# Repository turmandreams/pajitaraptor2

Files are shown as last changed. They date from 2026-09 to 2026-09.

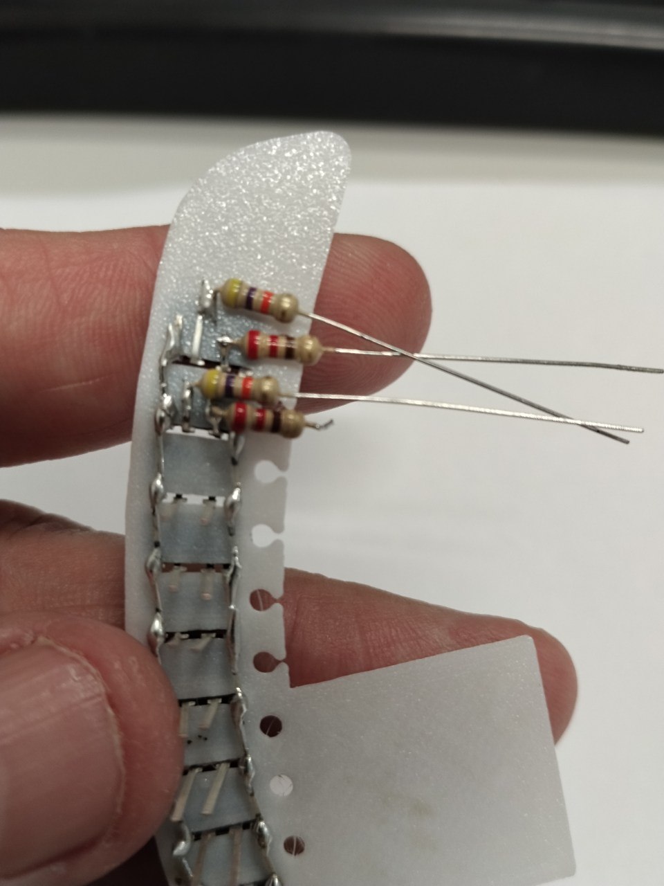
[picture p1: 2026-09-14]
images/06.jpg

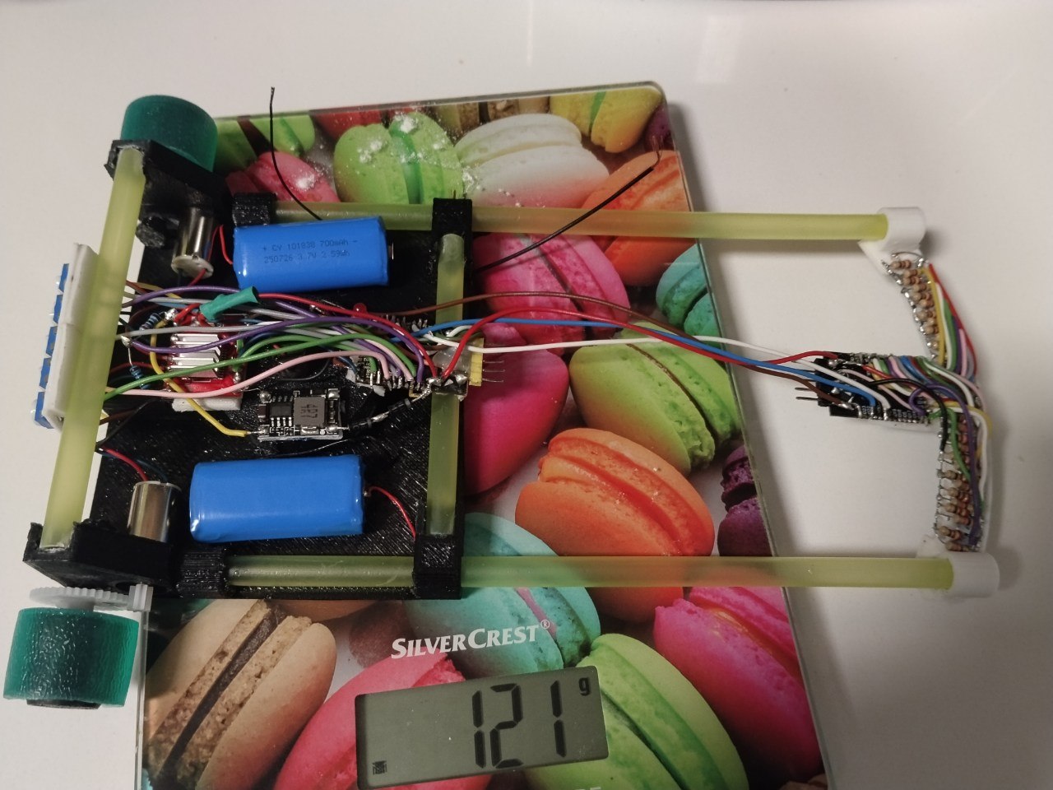
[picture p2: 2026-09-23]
images/32.jpg

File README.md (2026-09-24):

INFORMACIÓN
----------------------

Pajitaraptor 2.0 es un robot siguelineas evolución de Pajitaraptor. La idea es hacer un robot siguelineas lo más rápido posible con los componentes que tengo actualmente.

En este repositorio, voy a poner todos los archivos 3D, código fuente , esquemáticos, fotografías y vídeos explicativos del proceso de construcción del robot. 

Si el robot funciona bien, en el futuro realizaré una PCB, para que sea más fácil replicarlo...

PAJITARAPTOR 2.0 VIDEOS
----------------------

(https://www.youtube.com/shorts/T2Jo6v5rl2A)) 

(https://www.youtube.com/shorts/CzJLmVulj7A)) 

(https://www.youtube.com/shorts/VmxY9THQH6k)) 

(https://www.youtube.com/shorts/2Kd2S3cPOpA)) 

(https://www.youtube.com/shorts/im3EgLPvTIs)) 

(https://www.youtube.com/shorts/bMzzeWZkE-k)) 

(https://www.youtube.com/shorts/C7v8effX4s4)) 

(https://www.youtube.com/shorts/2WoTrkFVUT8)) 

(https://www.youtube.com/shorts/3bNs3Pc4z7s)) 

(https://www.youtube.com/shorts/3i1-s1l6Brc))

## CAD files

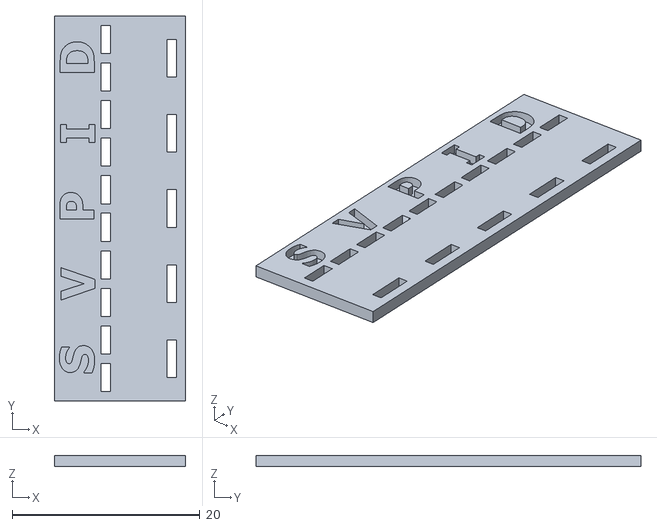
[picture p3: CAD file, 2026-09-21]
stl/pot.stl
14.0 x 41.0 x 1.20

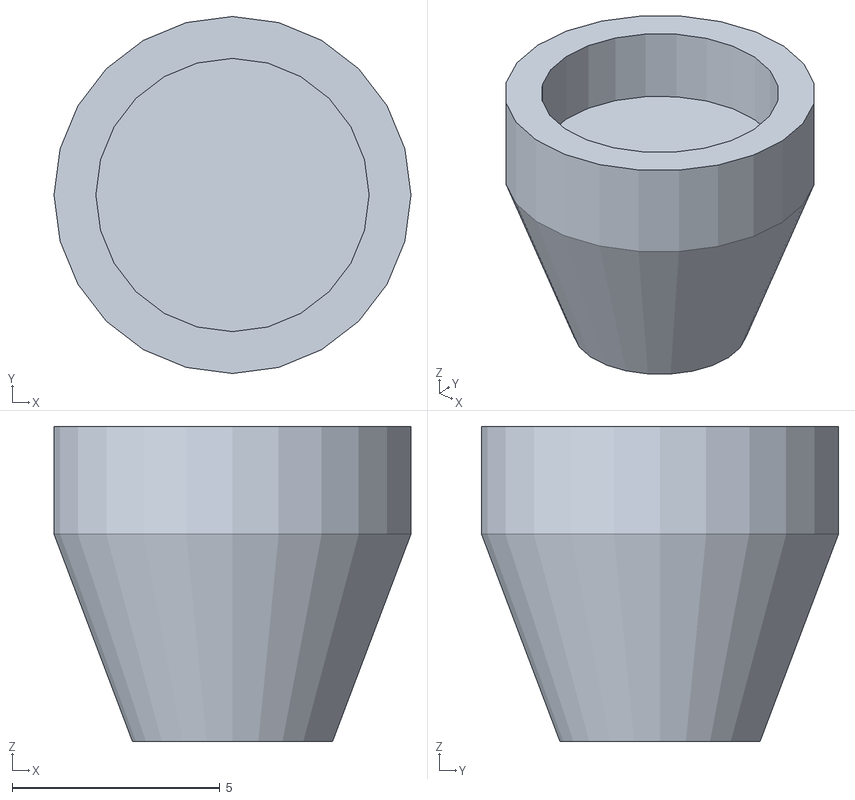
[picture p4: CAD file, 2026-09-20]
stl/imanes.stl
8.60 x 8.60 x 7.60

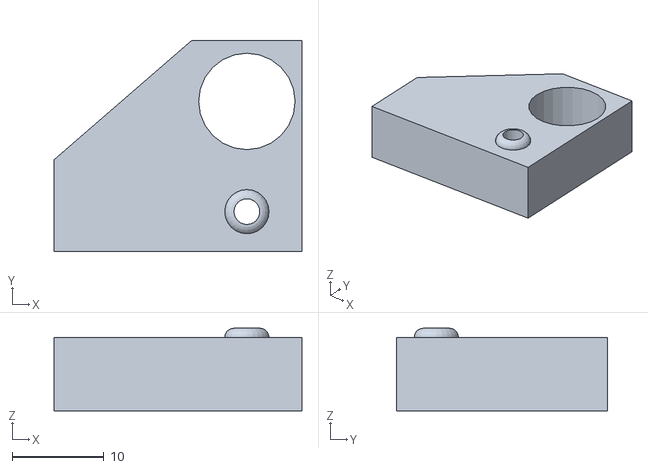
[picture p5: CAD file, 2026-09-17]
stl/soportemotorI.stl
27.0 x 23.0 x 9.00

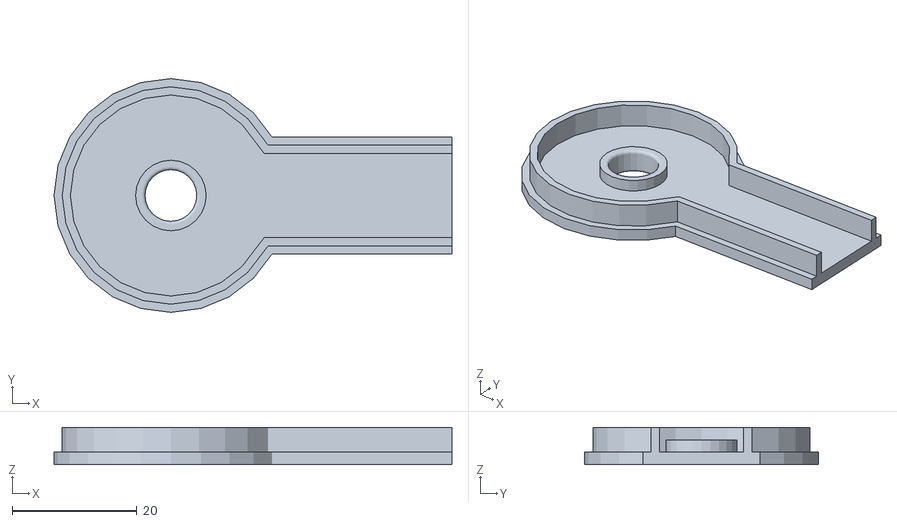
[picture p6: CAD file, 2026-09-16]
stl/tapaventilador.stl
63.7 x 37.4 x 6.00

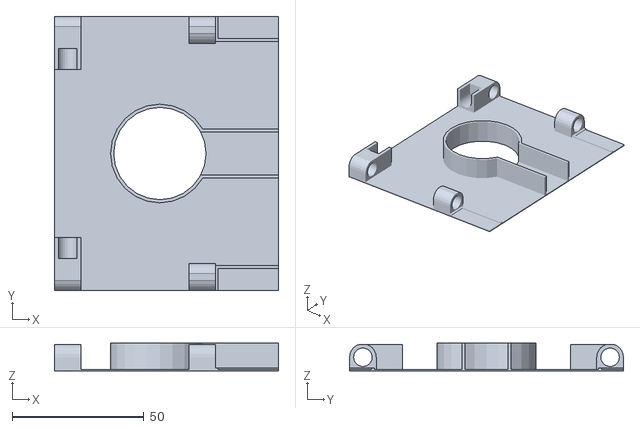
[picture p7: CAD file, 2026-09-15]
stl/base.stl
85.0 x 103.9 x 10.6

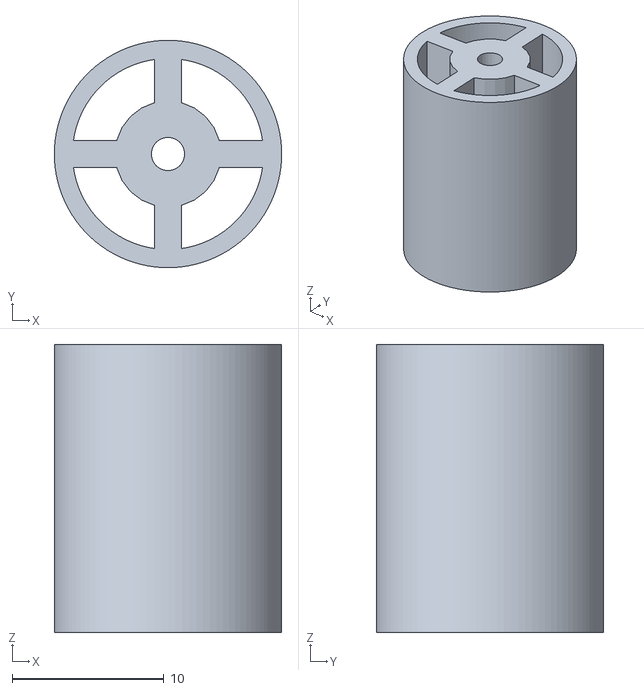
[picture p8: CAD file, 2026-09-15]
stl/rueda.stl
15.0 x 15.0 x 19.0

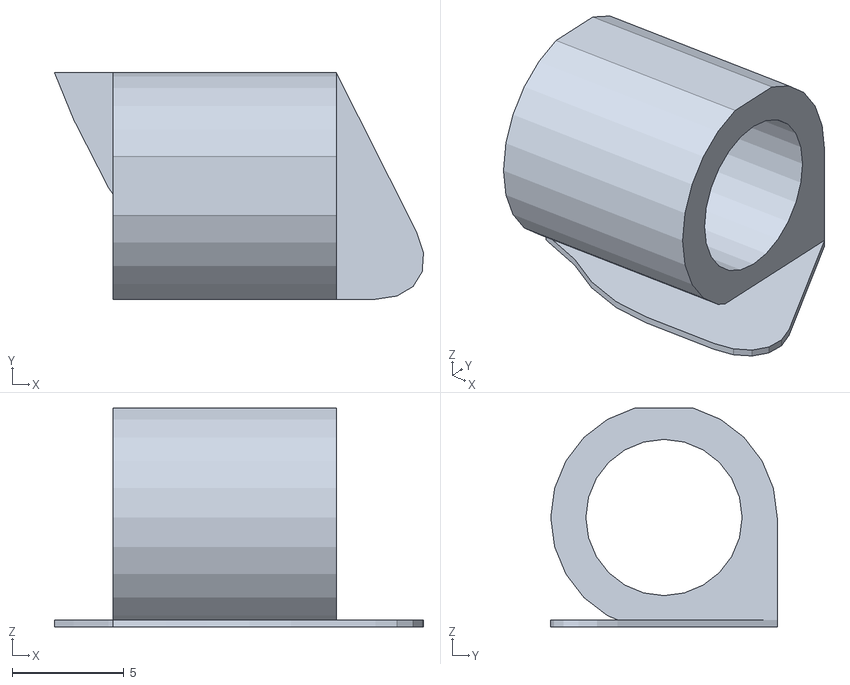
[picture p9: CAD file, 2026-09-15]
stl/soportepajitaDI.stl
16.5 x 10.1 x 9.80

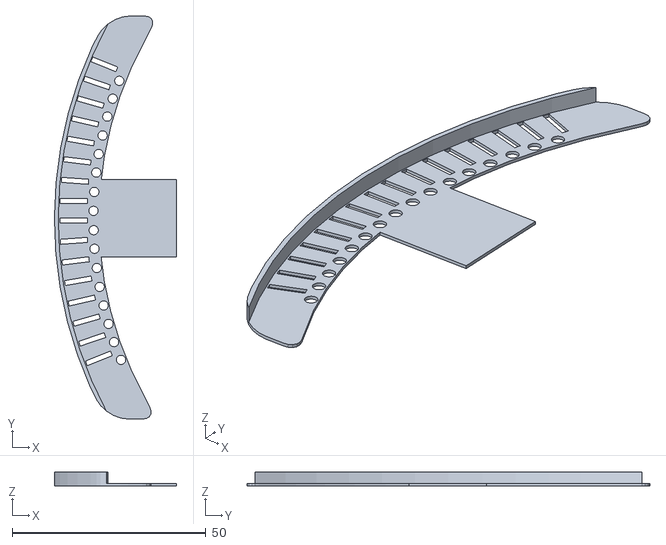
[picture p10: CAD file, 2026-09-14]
stl/arraysensores.stl
31.5 x 103.9 x 3.60

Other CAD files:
stl/soportemotorD.stl
stl/soportepajitaDD.stl
stl/arraysensores.skp
stl/base.skp
stl/imanes.skp
stl/pot.skp
stl/rueda.skp
stl/soportemotorD.skp
stl/soportemotorI.skp
stl/soportepajitaDD.skp
stl/soportepajitaDI.skp
stl/tapaventilador.skp

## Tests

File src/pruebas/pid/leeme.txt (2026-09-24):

 Detalles importantes

Sentido de giro: si al poner solo Kp el robot se aleja de la línea en lugar de corregir, cambia el signo (velIzq = VEL_BASE - correccion, velDer = VEL_BASE + correccion). Lo mismo si un motor gira al revés: intercambia sus IN1/IN2.
Pines ADC: usa pines de ADC1 (GPIO 32–39) para los potenciómetros. ADC2 deja de funcionar si activas WiFi o Bluetooth.
Versión del core: ledcAttach(pin, freq, res) y ledcWrite(pin, duty) son de la versión 3.x. Si usas la 2.x, sería ledcSetup(canal, freq, res) + ledcAttachPin(pin, canal) y ledcWrite(canal, duty).
Marcha atrás: permito velocidades negativas para que en curvas cerradas una rueda pueda frenar o invertir. Si no lo quieres, cambia el constrain a 0, 255.

Cómo ajustarlo con los potenciómetros

Pon Ki y Kd a cero. Sube Kp hasta que el robot siga la línea pero oscile.
Sube Kd poco a poco hasta que desaparezcan las oscilaciones.  
Ki normalmente se deja a cero o muy bajo en siguelíneas. Solo ayuda si el robot tiende a ir siempre desplazado hacia un lado.
Cuando lo tengas estable, sube VEL_BASE y reajusta.

Si ves que el potenciómetro de Kp o Kd se queda corto (o que todo el ajuste útil ocurre en una zona muy pequeña del giro), cambia KP_MAX o KD_MAX para ganar resolución donde la necesitas.

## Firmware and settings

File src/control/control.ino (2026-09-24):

#include <Wire.h>

#define SDA_PIN 21
#define SCL_PIN 26
#define SLAVE_ADDR 0x08

const int pinled=2;

const int pinAIN1 = 4;
const int pinAIN2 = 16;
const int pinPWMA = 17;


const int pinBIN1 = 15;
const int pinBIN2 = 12; 
const int pinPWMB = 27;  


const int pinsuccion = 13;  

const int frecuencia = 20000; 
const int resolucion = 8;    

// Asignación de canales de hardware obligatorios en v2.x
const int canalMotorA = 0;
const int canalMotorB = 1;


// ---------- Rangos máximos de cada constante ----------
// Kp: con error 750 y Kp=0.5 -> corrección 375 (satura sobrada)
const float KP_MAX = 0.5;
const float KI_MAX = 0.005;
const float KD_MAX = 5.0;

// ---------- Parámetros del robot ----------
int   VEL_BASE = 150;      // velocidad en recta (0..255)
const float INTEGRAL_MAX = 20000; // anti-windup

float Kp = 0, Ki = 0, Kd = 0;
float integral = 0;
float errorAnterior = 0;
unsigned long tAnterior = 0;
unsigned long tPots = 0;

const int canalSuccion = 2;

const int pinBateria = 36; 

// Factor para R1=220k y R2=100k -> (220+100)/100 = 3.2
const float factorDivisor = 3.2; 

// Voltaje de referencia real del ESP32 (típicamente 3.3V)
const float VREF = 3.3; 


volatile float receivedFloat = 0.0f;
volatile bool newData = false;

int contador=-1;

int tiempo=0;

int succion = 0;
int p_pid = 0;
int i_pid = 0; 
int d_pid = 0;

int tiemposensores=0;

boolean corre=false;




void medirbateria(){

 int valorADC = analogRead(pinBateria);
  
  // Convertir el valor de 8 bits (0-255) a voltaje en el pin (0 - 3.3V)
  float voltiosPin = (valorADC * VREF) / 255.0;
  
  // Calcular el voltaje real de la batería usando el divisor de tensión
  float voltajeBateria = voltiosPin * factorDivisor;
  
  // Calcular el porcentaje de carga (Batería 2S: 6.4V vacía a 8.4V llena)
  float porcentaje = ((voltajeBateria - 6.4) / (8.4 - 6.4)) * 100.0;
  
  // Limitar el porcentaje entre 0 y 100%
  if (porcentaje > 100) porcentaje = 100;
  if (porcentaje < 0) porcentaje = 0;

  // Imprimir los resultados
  Serial.print("Lectura ADC (8-bit): ");
  Serial.print(valorADC);
  Serial.print(" | Voltaje Batería: ");
  Serial.print(voltajeBateria, 2);
  Serial.print(" V | Carga: ");
  Serial.print(porcentaje, 0);
  Serial.println("%");

  
}

void leepotenciometros(){
  
    unsigned long sumS = 0;
    unsigned long sumV = 0;
    unsigned long sumP = 0;
    unsigned long sumI = 0;
    unsigned long sumD = 0;

    for(int k = 0; k < 100; k++){
        sumS += (255-analogRead(34));
        sumV += (255-analogRead(35));
        sumP += (255-analogRead(32));
        sumI += (255-analogRead(33));
        sumD += (255-analogRead(39));
    }

    succion = sumS / 100;
    VEL_BASE = sumV / 100;
    p_pid = sumP / 100;
    i_pid = sumI / 100;
    d_pid = sumD / 100;


    Kp = p_pid / 255.0 * KP_MAX;
    Ki = i_pid / 255.0 * KI_MAX;
    Kd = d_pid / 255.0 * KD_MAX;

    
    // Mostrar resultados en el Monitor Serie
    Serial.print("Succion : "); Serial.println(succion);
    Serial.print("Velocidad Base: "); Serial.println(VEL_BASE);
    Serial.print("P : "); Serial.println(p_pid);
    Serial.print("I : "); Serial.println(i_pid);
    Serial.print("D : "); Serial.println(d_pid);
    Serial.println("");
    
    
    //ponemos el pwm en el ventilador de succion
    if(succion<20){ succion=0;}
    succion=succion/5;
    
    
    
}

// velocidad: -255..255 (negativo = marcha atrás)
void motor(int canal, int in1, int in2, int velocidad) {
  velocidad = constrain(velocidad, -255, 255);
  if (velocidad >= 0) {
    digitalWrite(in1, HIGH);
    digitalWrite(in2, LOW);
  } else {
    digitalWrite(in1, LOW);
    digitalWrite(in2, HIGH);
  }
  ledcWrite(canal,abs(velocidad));
}

void pidmotores(float error){

  unsigned long ahora = micros();
  float dt = (ahora - tAnterior) / 1000.0;   // en milisegundos
  tAnterior = ahora;
  if (dt <= 0) dt = 1;


  // --- PID ---
  integral += error * dt;
  integral = constrain(integral, -INTEGRAL_MAX, INTEGRAL_MAX);

  float derivada = (error - errorAnterior) / dt;
  errorAnterior = error;

  float correccion = Kp * error + Ki * integral + Kd * derivada;

  // --- Aplicar a motores ---
  int velIzq = VEL_BASE + correccion;
  int velDer = VEL_BASE - correccion;

  motor(canalMotorA,pinAIN2,pinAIN1, velIzq);
  motor(canalMotorB,pinBIN1,pinBIN2, velDer);

  ledcWrite(canalSuccion,succion);
    
}

void receiveEvent(int bytesCount) {
  
  // Comprobamos que hayan llegado exactamente 4 bytes (tamaño de un float)
  if (bytesCount == sizeof(float)) {
  
    digitalWrite(pinled,HIGH);
    corre=true;

  
    uint8_t buffer[sizeof(float)];
    
    for (int i = 0; i < sizeof(float); i++) {
      buffer[i] = Wire.read();
    }
    
    // Copiamos los bytes directamente a la variable float en memoria
    memcpy((void*)&receivedFloat, buffer, sizeof(float));

    pidmotores(receivedFloat);

    tiemposensores=millis();

/*
    contador++;

    //Serial.println(receivedFloat, 2);
    if(contador==0){  tiempo=millis(); }
    else if(contador==100){
        contador=-1;
        int valor=millis()-tiempo;
        Serial.print("Ha tardado : ");
        Serial.println(valor);
        Serial.print("Posicion : ");
        Serial.println(receivedFloat, 2);
    }
*/
    
  } else {
    // Si llegan bytes extras, vaciamos el bus
    while (Wire.available()) Wire.read();
  }

  
}

void espera(int t){
  boolean estado=corre;
  for(int i=0;i<t;i++){
        if(corre){
            if((millis()-tiemposensores)>10){ 
              corre=false;
              digitalWrite(pinled,LOW);              
            }
        }
        
        if(estado!=corre){ break; }
        delay(1);
  }
  
}

void setup() {
  
  Serial.begin(115200);
 
  pinMode(pinAIN1, OUTPUT);
  pinMode(pinAIN2, OUTPUT);
  pinMode(pinBIN1, OUTPUT);
  pinMode(pinBIN2, OUTPUT);
  pinMode(pinPWMA, OUTPUT);
  pinMode(pinPWMB, OUTPUT);

  
  ledcSetup(canalMotorA, frecuencia, resolucion); 
  ledcSetup(canalMotorB, frecuencia, resolucion); 
  ledcSetup(canalSuccion, frecuencia, resolucion); 
  
  
  ledcAttachPin(pinPWMA, canalMotorA); 
  ledcAttachPin(pinPWMB, canalMotorB); 

  ledcAttachPin(pinsuccion,canalSuccion); 
  
  pinMode(pinled,OUTPUT);
  digitalWrite(pinled,LOW);
    
  analogReadResolution(8); 

  delay(2000);
  leepotenciometros();
  delay(2000);
  
  Wire.begin(SLAVE_ADDR, SDA_PIN, SCL_PIN, 1000000);
  Wire.onReceive(receiveEvent);
  
}

void loop() {

  /*
  if(corre){

    ledcWrite(canalMotorA, velocidad); 
    ledcWrite(canalMotorB, velocidad); 

    //Hacia atras
    digitalWrite(pinAIN2, LOW);
    digitalWrite(pinAIN1, HIGH);
    digitalWrite(pinBIN1, LOW);
    digitalWrite(pinBIN2, HIGH);
    espera(2000); 

  }
*/
  espera(2);
  
  if(!corre){

    leepotenciometros();
    medirbateria();
    
    motor(canalMotorA,pinAIN2,pinAIN1,0);
    motor(canalMotorB,pinBIN1,pinBIN2,0);
    ledcWrite(canalSuccion,0);
    espera(100); 
    
  }
  
  
}

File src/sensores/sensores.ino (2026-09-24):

#include <Arduino.h>
#include <IRremoteESP8266.h>
#include <IRrecv.h>
#include <IRutils.h>


const uint16_t RECV_PIN = 5; 

IRrecv irrecv(RECV_PIN);
decode_results results;
const int pinled=19;

#include <Wire.h>

#define SDA_PIN 21
#define SCL_PIN 22
#define SLAVE_ADDR 0x08
#define I2C_SPEED 1000000  // 1 MHz (Fast Mode+)

int pines[]={36,39,34,35,32,33,25,26,27,14,12,13,15,2,0,4};

float posicion=0.0;

boolean funcionando=false;

int tiempo=0;

int tiempoparpadeo=0;
boolean ledparpadeo=false;


void leesensores(){
    
    float sensores[16];
    float suma = 0;
    float sumaPesos = 0;

    int val=0;

   // String dato="";
    
    for(int i=0;i<16;i++){      
        val=255-analogRead(pines[i]);
      //  dato+=val;
        sensores[i]=(float)val;
     //   if(i!=15){ dato+=","; }
    }
    
  //  Serial.println(dato);

   
    int peso=-8.0;

    int num=0;
    for (int i = 0; i < 16; i++) {        
                
        if(sensores[i]>30){ 
          suma += sensores[i];
          sumaPesos += sensores[i] * peso;  
          num++;
        }
        peso++;        
    }

        
    float posicion2 = sumaPesos/suma;
    if(num!=0){  
        posicion=(posicion2*100); 
        posicion+=50.0;
    }      
    
}


void setup() {
  

  Serial.begin(115200);
  
  
  
  irrecv.enableIRIn(); 
  
  // Inicializa I2C con pines específicos y frecuencia máxima
  Wire.begin(SDA_PIN, SCL_PIN);
  Wire.setClock(I2C_SPEED);

  analogReadResolution(8);
    
  for(int i=0;i<16;i++){  pinMode(pines[i],INPUT);  }

  pinMode(pinled,OUTPUT);


    
}

void loop() {

  if (irrecv.decode(&results)) {
    irrecv.resume(); 
  
    if((millis()-tiempo)>300){    
        funcionando=!funcionando;
        if(funcionando){ digitalWrite(pinled,HIGH);}
        else{ digitalWrite(pinled,LOW);}
    }

    tiempo=millis();
    
  }

  if(funcionando){

      leesensores();
  
      Wire.beginTransmission(SLAVE_ADDR);
  
      Wire.write((uint8_t*)&posicion, sizeof(float));
  
      Wire.endTransmission();

      //delay(1);
      
  }else{

      if((millis()-tiempoparpadeo)>1000) {

          ledparpadeo=!ledparpadeo;
          digitalWrite(pinled,ledparpadeo);
          tiempoparpadeo=millis();
        
      }

    
  }
  
}
